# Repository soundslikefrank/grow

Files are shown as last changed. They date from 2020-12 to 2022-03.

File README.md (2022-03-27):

# GROW

A Eurorack genetic sequencer.

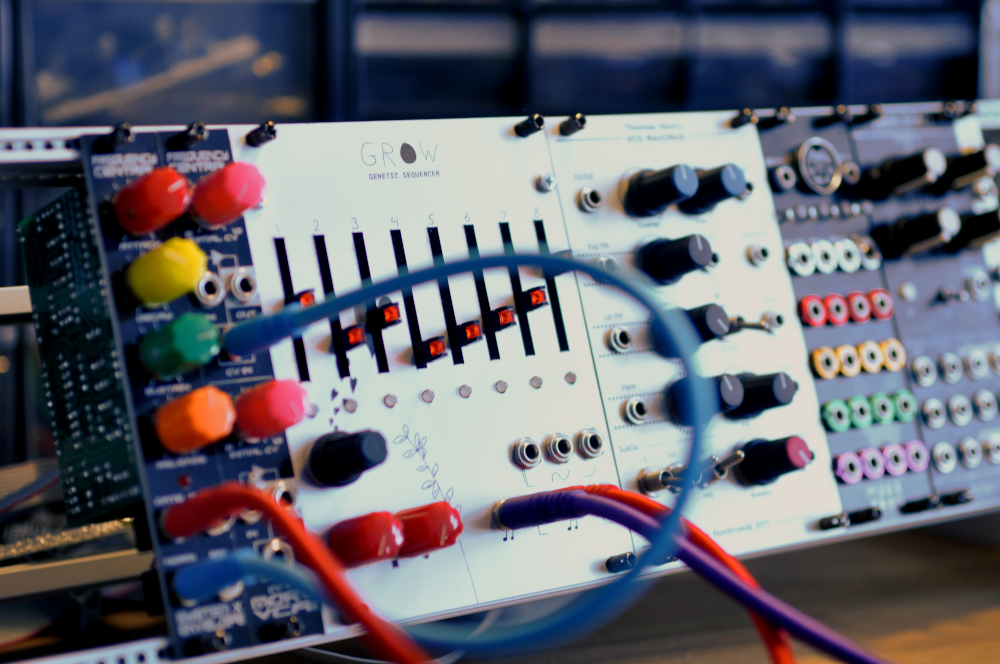
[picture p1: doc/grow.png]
grow


This repository serves as the home for its MCU code and hardware schematics.

There will be a lot more info soon.

## To build

```sh
git submodule update --init --recursive # if not cloned recursively
brew install cmake
brew install --cask gcc-arm-embedded
mkdir build && cd build
cmake -DCMAKE_TOOLCHAIN_FILE=../arm-none-eabi-gcc.cmake ..
make
```

## LICENSE

GNU General Public License v3.0

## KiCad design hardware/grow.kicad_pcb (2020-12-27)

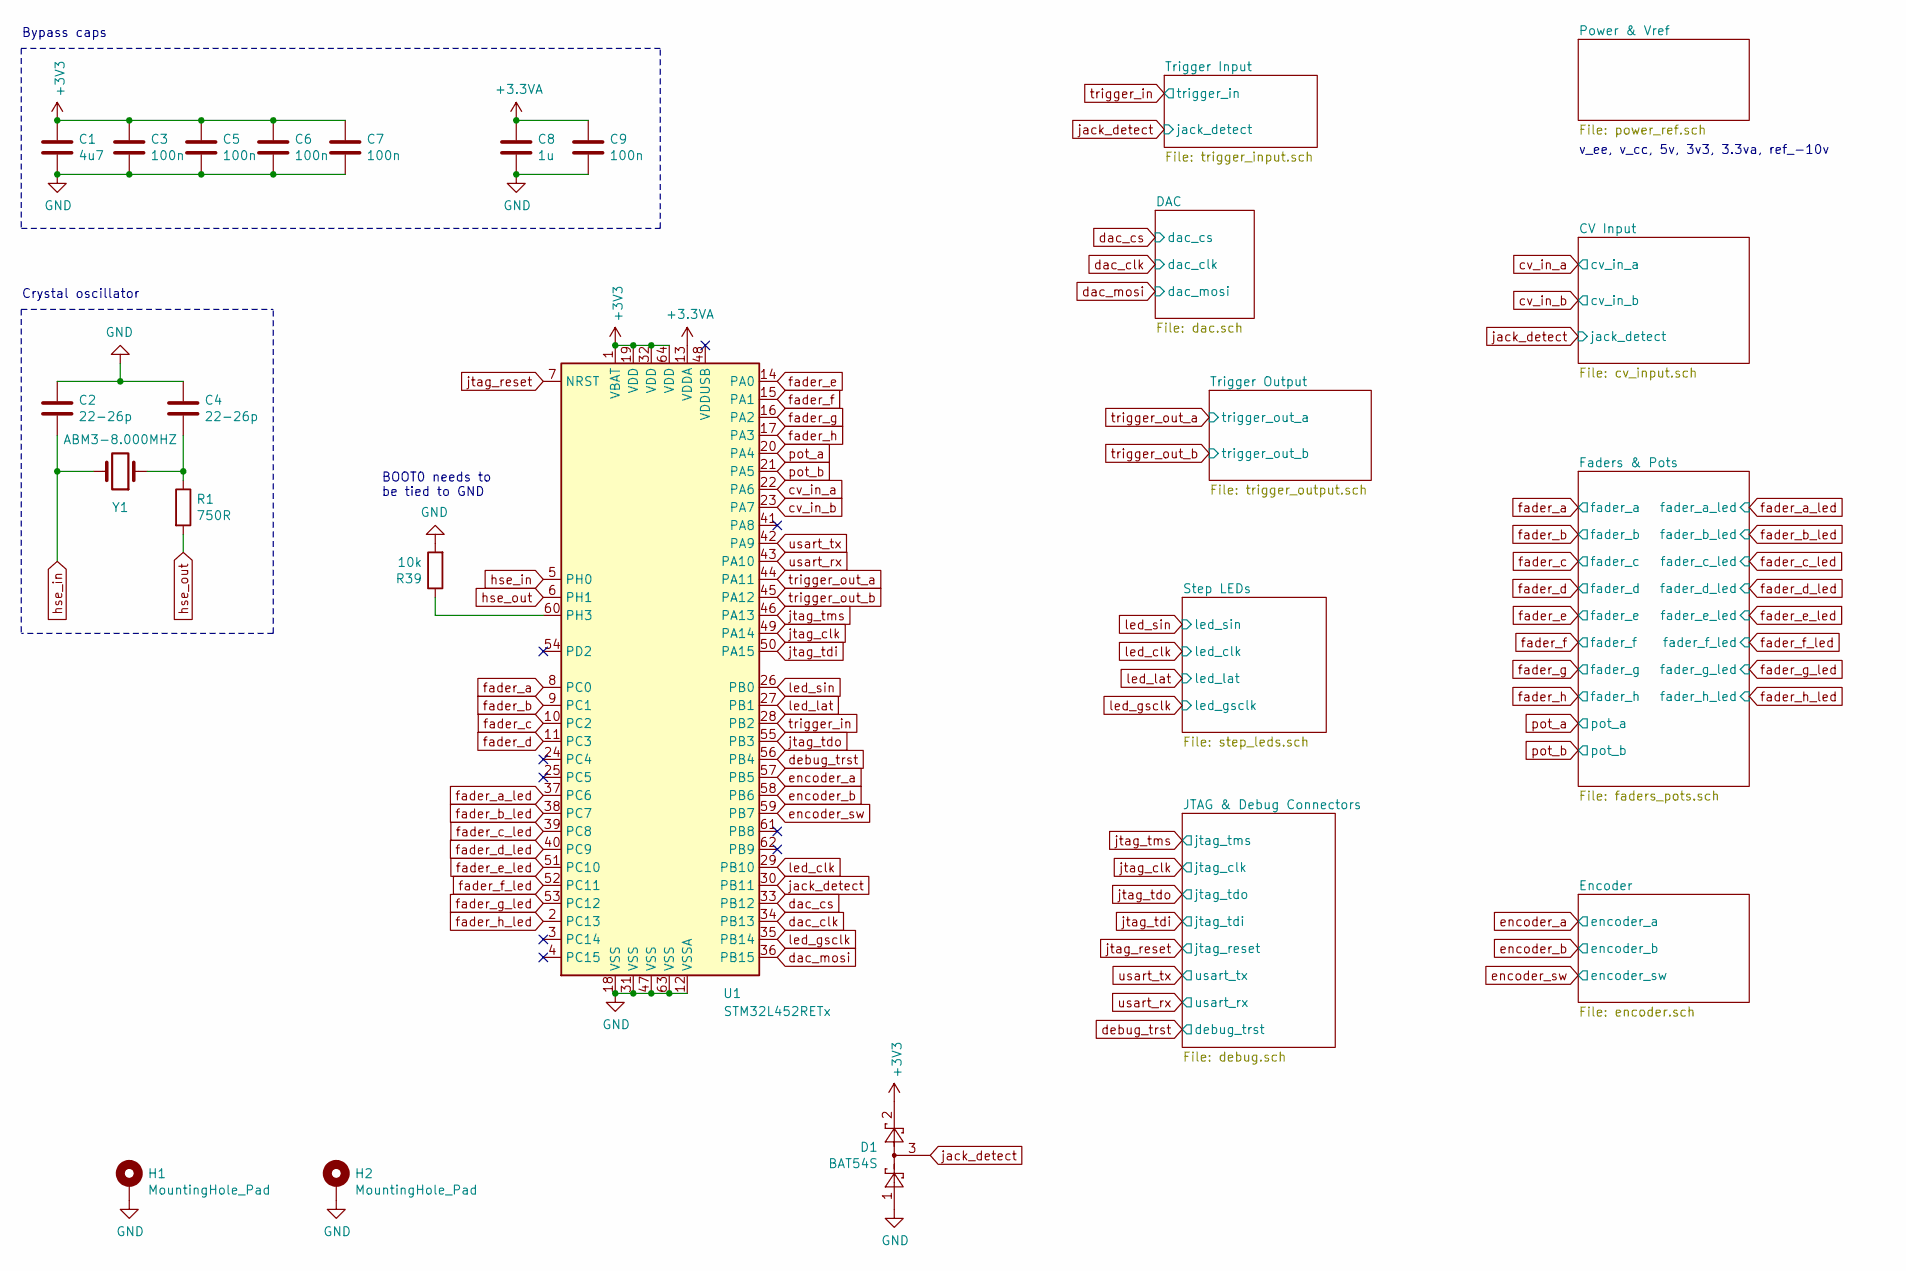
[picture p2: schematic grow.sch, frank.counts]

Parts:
C1: 4u7; C_0603_1608Metric; LCSC Part # C19666
C2, C4: 22-26p; C_0603_1608Metric; LCSC Part # C388039
C3, C5, C6, C7, C9: 100n; C_0603_1608Metric; LCSC Part # C14663
C8: 1u; C_0603_1608Metric; LCSC Part # C15849
D1: BAT54S; SOT-23
H1, H2: MountingHole_Pad; MountingHole_3.2mm_M3
R1: 750R; R_0603_1608Metric; LCSC Part # C23241
R39: 10k; R_0603_1608Metric; LCSC Part # C25804
U1: STM32L452RETx; LQFP-64_10x10mm_P0.5mm
Y1: ABM3-8.000MHZ; Crystal_SMD_Abracon_ABM3-2Pin_5.0x3.2mm_HandSoldering

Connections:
3v3a: C8.1, C9.1, U1.13 (VDDA); also elsewhere on the board
GND: C1.2, C2.1, C3.2, C4.1, C5.2, C6.2, C7.2, C8.2, C9.2, D1.1, H1.1, H2.1, R39.2, U1.12 (VSSA), U1.18 (VSS), U1.31 (VSS), U1.47 (VSS), U1.63 (VSS); also elsewhere on the board
unnamed: C4.2, R1.1, Y1.1
unnamed: R39.1, U1.60 (PH3)
cv_in_a: U1.22 (PA6); also elsewhere on the board
cv_in_b: U1.23 (PA7); also elsewhere on the board
dac_clk: U1.34 (PB13); also elsewhere on the board
dac_cs: U1.33 (PB12); also elsewhere on the board
dac_mosi: U1.36 (PB15); also elsewhere on the board
debug_trst: U1.56 (PB4); also elsewhere on the board
encoder_a: U1.57 (PB5); also elsewhere on the board
encoder_b: U1.58 (PB6); also elsewhere on the board
encoder_sw: U1.59 (PB7); also elsewhere on the board
fader_a: U1.8 (PC0); also elsewhere on the board
fader_a_led: U1.37 (PC6); also elsewhere on the board
fader_b: U1.9 (PC1); also elsewhere on the board
fader_b_led: U1.38 (PC7); also elsewhere on the board
fader_c: U1.10 (PC2); also elsewhere on the board
fader_c_led: U1.39 (PC8); also elsewhere on the board
fader_d: U1.11 (PC3); also elsewhere on the board
fader_d_led: U1.40 (PC9); also elsewhere on the board
fader_e: U1.14 (PA0); also elsewhere on the board
fader_e_led: U1.51 (PC10); also elsewhere on the board
fader_f: U1.15 (PA1); also elsewhere on the board
fader_f_led: U1.52 (PC11); also elsewhere on the board
fader_g: U1.16 (PA2); also elsewhere on the board
fader_g_led: U1.53 (PC12); also elsewhere on the board
fader_h: U1.17 (PA3); also elsewhere on the board
fader_h_led: U1.2 (PC13); also elsewhere on the board
hse_in: C2.2, U1.5 (PH0), Y1.2
hse_out: R1.2, U1.6 (PH1)
jack_detect: D1.3, U1.30 (PB11); also elsewhere on the board
jtag_clk: U1.49 (PA14); also elsewhere on the board
jtag_reset: U1.7 (NRST); also elsewhere on the board
jtag_tdi: U1.50 (PA15); also elsewhere on the board
jtag_tdo: U1.55 (PB3); also elsewhere on the board
jtag_tms: U1.46 (PA13); also elsewhere on the board
led_clk: U1.29 (PB10); also elsewhere on the board
led_gsclk: U1.35 (PB14); also elsewhere on the board
led_lat: U1.27 (PB1); also elsewhere on the board
led_sin: U1.26 (PB0); also elsewhere on the board
pot_a: U1.20 (PA4); also elsewhere on the board
pot_b: U1.21 (PA5); also elsewhere on the board
trigger_in: U1.28 (PB2); also elsewhere on the board
trigger_out_a: U1.44 (PA11); also elsewhere on the board
trigger_out_b: U1.45 (PA12); also elsewhere on the board
usart_rx: U1.43 (PA10); also elsewhere on the board
usart_tx: U1.42 (PA9); also elsewhere on the board

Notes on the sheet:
Bypass caps
Crystal oscillator
v_ee, v_cc, 5v, 3v3, 3.3va, ref_-10v
BOOT0 needs to be tied to GND

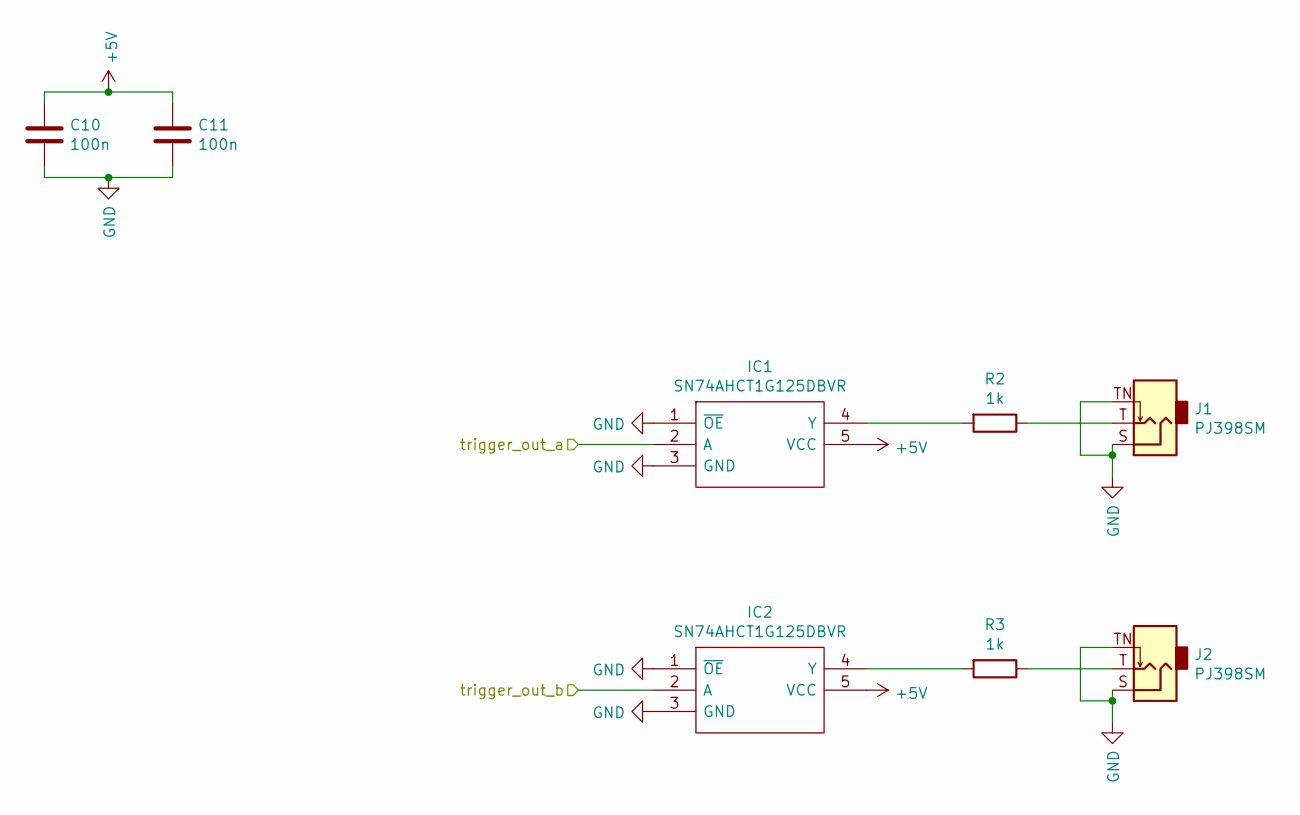
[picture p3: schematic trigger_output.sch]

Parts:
C10, C11: 100n; C_0603_1608Metric; LCSC Part # C14663
IC1, IC2: SN74AHCT1G125DBVR; SOT95P280X145-5N; Manufacturer_Part_Number SN74AHCT1G125DBVR; Mouser Part Number 595-SNAHCT1G125DBVR
J1, J2: PJ398SM; Jack_3.5mm_QingPu_WQP-PJ398SM_Vertical_CircularHoles
R2, R3: 1k; R_0603_1608Metric; LCSC Part # C21190

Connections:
+5V: C10.1, C11.1, IC1.5 (VCC), IC2.5 (VCC); also elsewhere on the board
GND: C10.2, C11.2, IC1.1 (~OE), IC1.3 (GND), IC2.1 (~OE), IC2.3 (GND), J1.S, J1.TN, J2.S, J2.TN; also elsewhere on the board
unnamed: IC1.4 (Y), R2.2
unnamed: IC2.4 (Y), R3.2
unnamed: J1.T, R2.1
unnamed: J2.T, R3.1
trigger_out_a: IC1.2 (A); also elsewhere on the board
trigger_out_b: IC2.2 (A); also elsewhere on the board

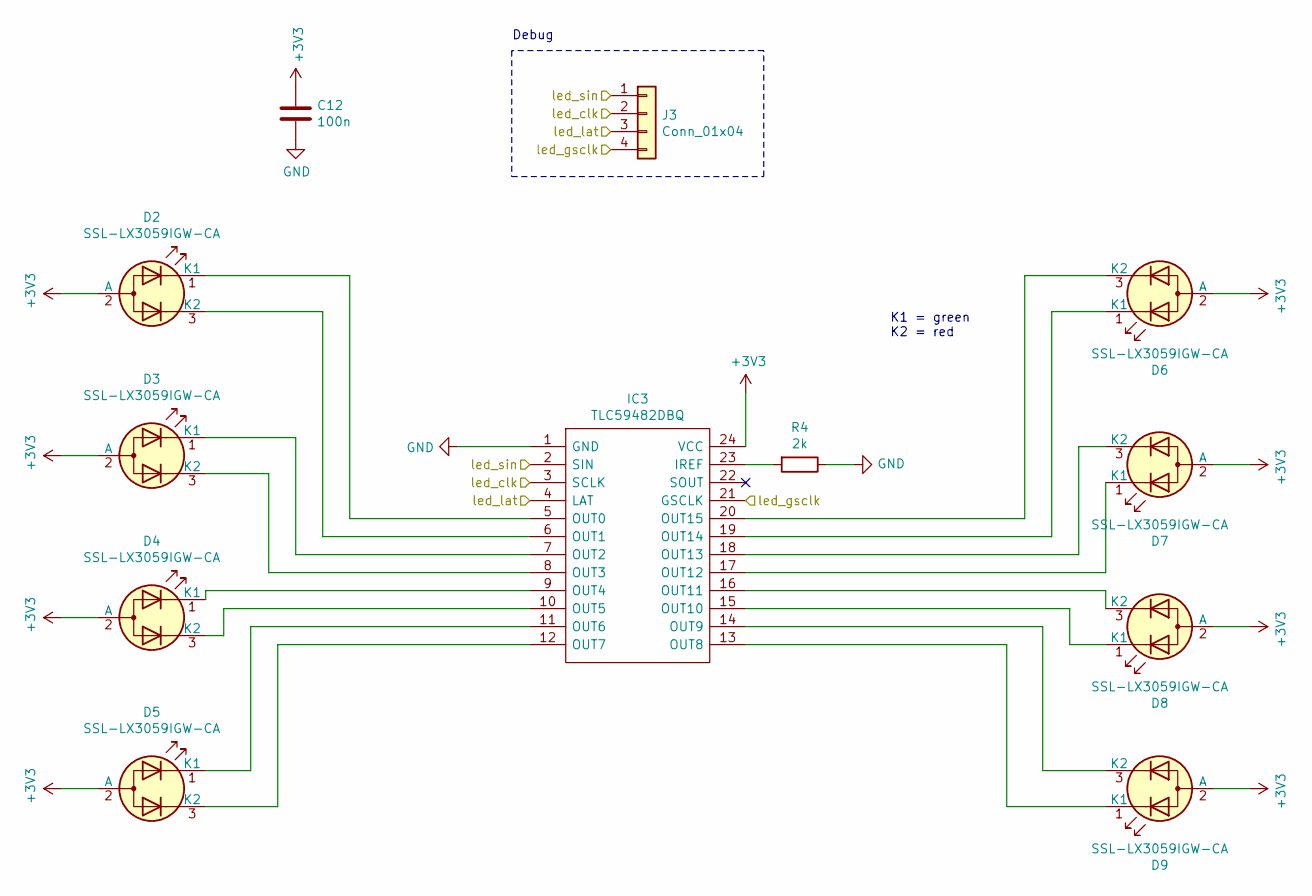
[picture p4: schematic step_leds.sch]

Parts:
C12: 100n; C_0603_1608Metric; LCSC Part # C14663
D2, D3, D4, D5, D6, D7, D8, D9: SSL-LX3059IGW-CA; LED_D3.0mm-3
IC3: TLC59482DBQ; SOP64P600X175-24N; Manufacturer_Part_Number TLC59482DBQ; Mouser Part Number 595-TLC59482DBQ
J3: Conn_01x04; PinHeader_1x04_P2.54mm_Vertical
R4: 2k; R_0603_1608Metric; LCSC Part # C22975

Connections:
GND: C12.2, IC3.1 (GND), R4.1; also elsewhere on the board
unnamed: D2.1 (K1), IC3.5 (OUT0)
unnamed: D2.3 (K2), IC3.6 (OUT1)
unnamed: D3.1 (K1), IC3.7 (OUT2)
unnamed: D3.3 (K2), IC3.8 (OUT3)
unnamed: D4.1 (K1), IC3.9 (OUT4)
unnamed: D4.3 (K2), IC3.10 (OUT5)
unnamed: D5.1 (K1), IC3.11 (OUT6)
unnamed: D5.3 (K2), IC3.12 (OUT7)
unnamed: D6.1 (K1), IC3.19 (OUT14)
unnamed: D6.3 (K2), IC3.20 (OUT15)
unnamed: D7.1 (K1), IC3.17 (OUT12)
unnamed: D7.3 (K2), IC3.18 (OUT13)
unnamed: D8.1 (K1), IC3.15 (OUT10)
unnamed: D8.3 (K2), IC3.16 (OUT11)
unnamed: D9.1 (K1), IC3.13 (OUT8)
unnamed: D9.3 (K2), IC3.14 (OUT9)
unnamed: IC3.23 (IREF), R4.2
led_clk: IC3.3 (SCLK), J3.2; also elsewhere on the board
led_gsclk: IC3.21 (GSCLK), J3.4; also elsewhere on the board
led_lat: IC3.4 (LAT), J3.3; also elsewhere on the board
led_sin: IC3.2 (SIN), J3.1; also elsewhere on the board

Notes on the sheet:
Debug
K1 = green K2 = red

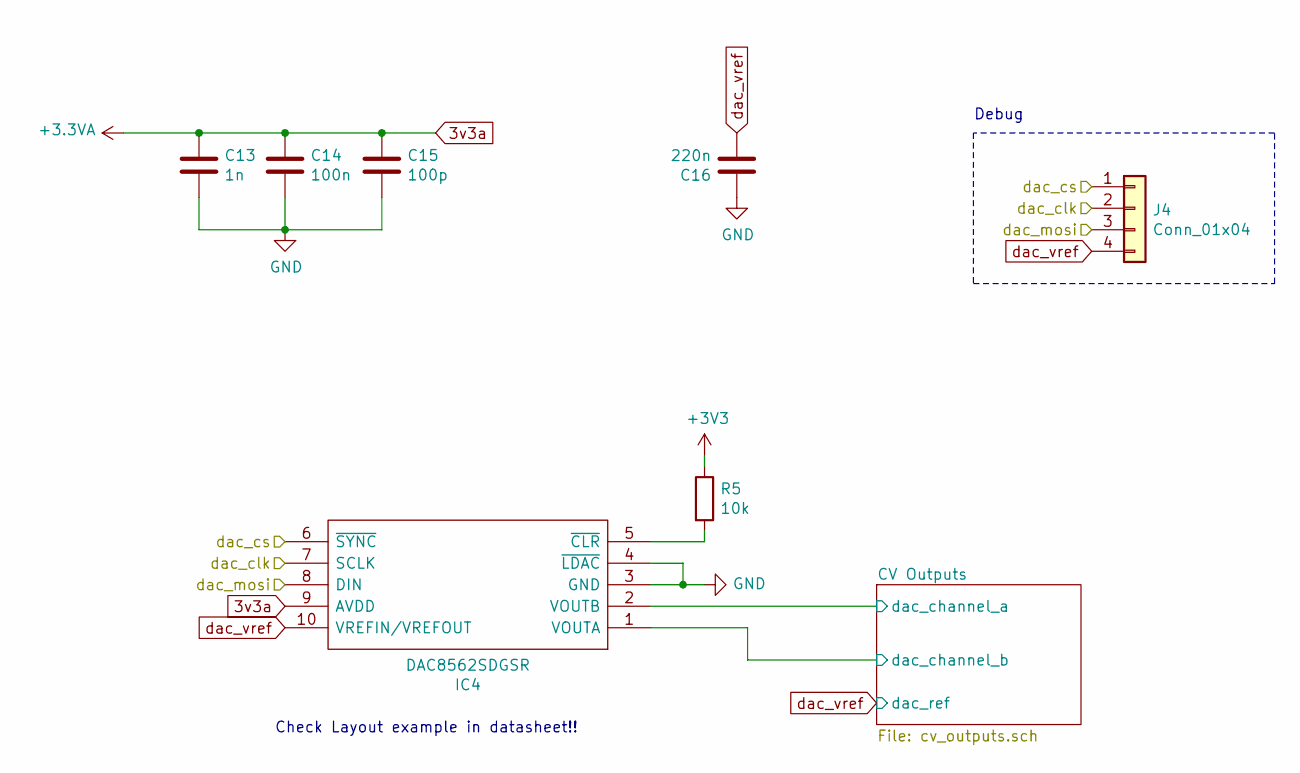
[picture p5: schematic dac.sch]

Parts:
C13: 1n; C_0603_1608Metric; LCSC Part # C1588
C14: 100n; C_0603_1608Metric; LCSC Part # C14663
C15: 100p; C_0603_1608Metric; LCSC Part # C14858
C16: 220n; C_0603_1608Metric; LCSC Part # C21120
IC4: DAC8562SDGSR; SOP50P490X110-10N; Manufacturer_Part_Number DAC8562SDGSR; Mouser Part Number 595-DAC8562SDGSR
J4: Conn_01x04; PinHeader_1x04_P2.54mm_Vertical
R5: 10k; R_0603_1608Metric; LCSC Part # C25804

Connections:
3v3a: C13.2, C14.1, C15.1, IC4.9 (AVDD); also elsewhere on the board
/DAC/CV Outputs/dac_channel_a: IC4.2 (VOUTB); also elsewhere on the board
/DAC/CV Outputs/dac_channel_b: IC4.1 (VOUTA); also elsewhere on the board
GND: C13.1, C14.2, C15.2, C16.2, IC4.3 (GND), IC4.4 (~LDAC); also elsewhere on the board
unnamed: IC4.5 (~CLR), R5.2
dac_clk: IC4.7 (SCLK), J4.2; also elsewhere on the board
dac_cs: IC4.6 (~SYNC), J4.1; also elsewhere on the board
dac_mosi: IC4.8 (DIN), J4.3; also elsewhere on the board
dac_vref: C16.1, IC4.10 (VREFIN/VREFOUT), J4.4; also elsewhere on the board

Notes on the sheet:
Check Layout example in datasheet!!
Debug

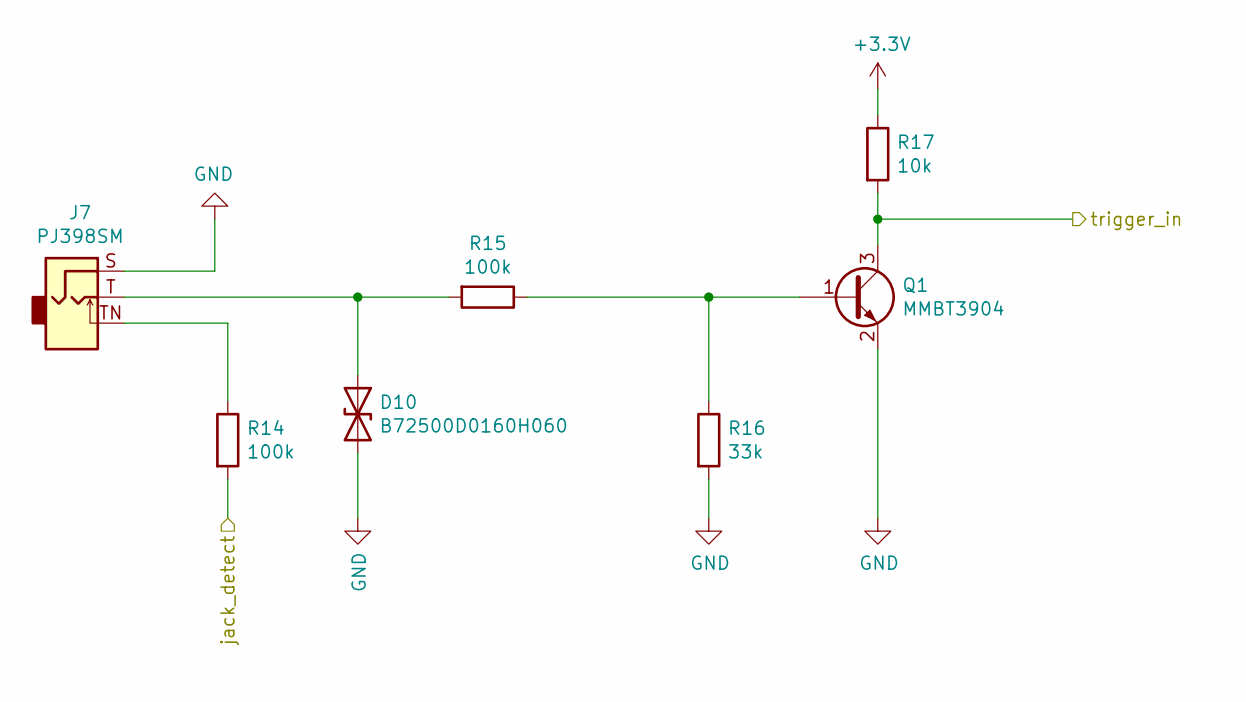
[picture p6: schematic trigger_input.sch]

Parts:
D10: B72500D0160H060; D_0603_1608Metric
J7: PJ398SM; Jack_3.5mm_QingPu_WQP-PJ398SM_Vertical_CircularHoles
Q1: MMBT3904; SOT-23; LCSC Part # C20526
R14, R15: 100k; R_0603_1608Metric; LCSC Part # C25803
R16: 33k; R_0603_1608Metric; LCSC Part # C4216
R17: 10k; R_0603_1608Metric; LCSC Part # C25804

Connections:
GND: D10.2 (A2), J7.S, Q1.2 (E), R16.2; also elsewhere on the board
unnamed: D10.1 (A1), J7.T, R15.2
unnamed: J7.TN, R14.1
unnamed: Q1.1 (B), R15.1, R16.1
jack_detect: R14.2; also elsewhere on the board
trigger_in: Q1.3 (C), R17.2; also elsewhere on the board

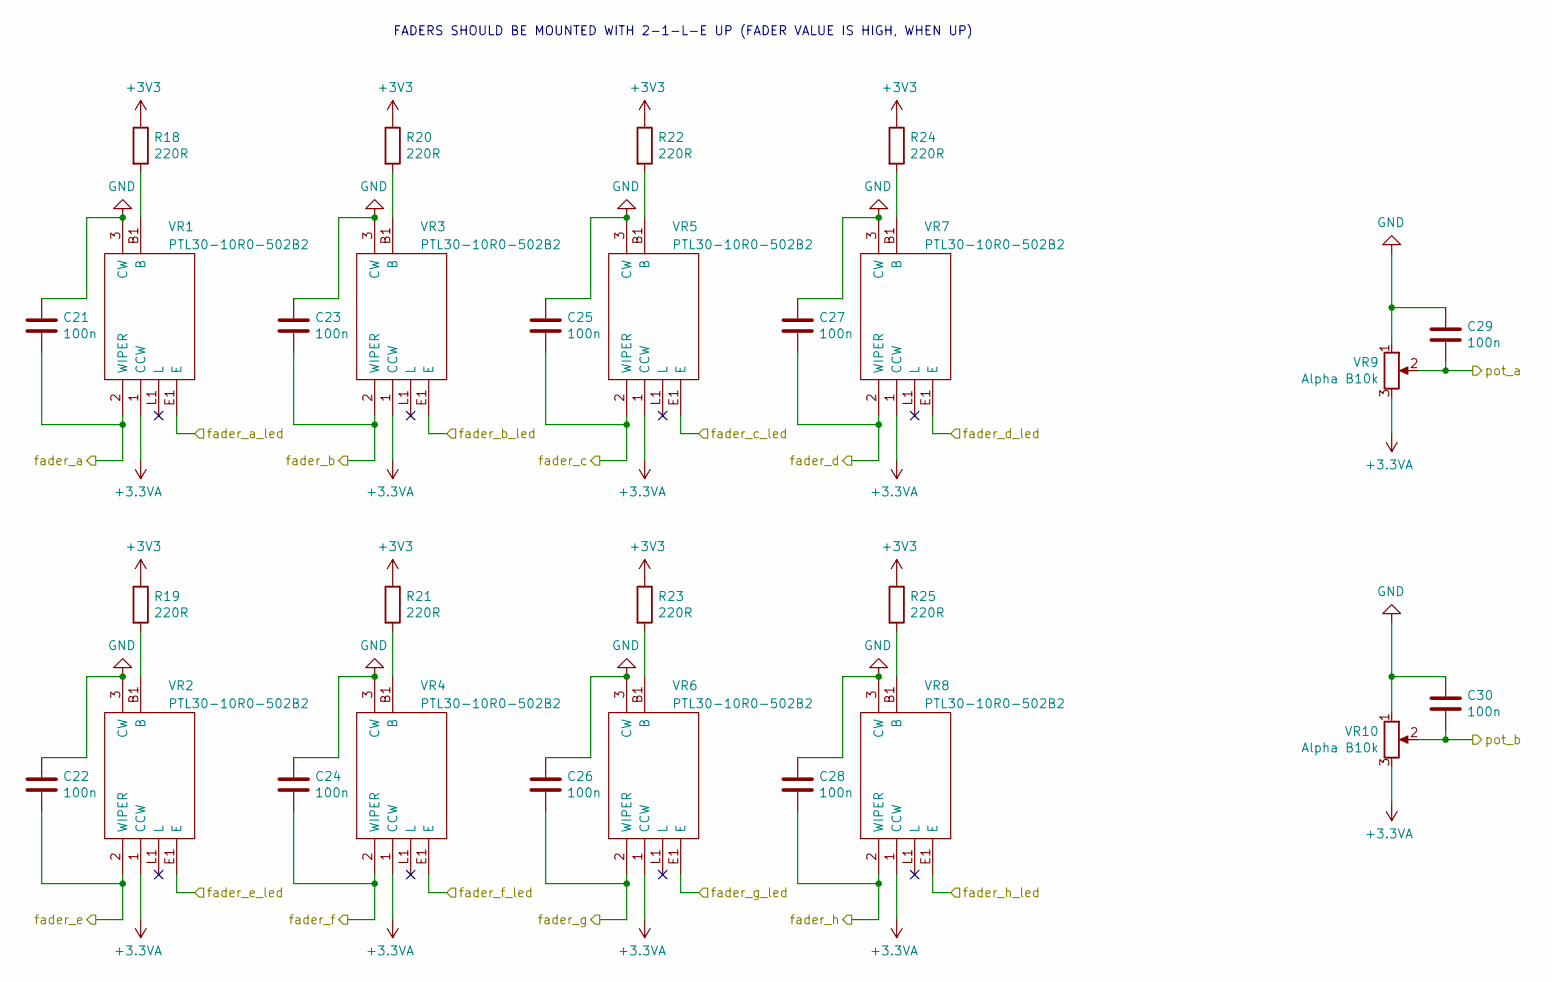
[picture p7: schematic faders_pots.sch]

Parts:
C21, C22, C23, C24, C25, C26, C27, C28, C29, C30: 100n; C_0603_1608Metric; LCSC Part # C14663
R18, R19, R20, R21, R22, R23, R24, R25: 220R; R_0603_1608Metric; LCSC Part # C22962
VR1, VR2, VR3, VR4, VR5, VR6, VR7, VR8: PTL30-10R0-502B2; PTL3010R1103B2; Manufacturer_Part_Number PTL30-10R0-502B2; Mouser Part Number 652-PTL30-10R0-502B2
VR9, VR10: Alpha B10k; Potentiometer_Alpha_RD901F-40-00D_Single_Vertical

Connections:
3v3a: VR1.1 (CCW), VR2.1 (CCW), VR3.1 (CCW), VR4.1 (CCW), VR5.1 (CCW), VR6.1 (CCW), VR7.1 (CCW), VR8.1 (CCW), VR9.3, VR10.3; also elsewhere on the board
GND: C21.1, C22.1, C23.1, C24.1, C25.1, C26.1, C27.1, C28.1, C29.1, C30.1, VR1.3 (CW), VR2.3 (CW), VR3.3 (CW), VR4.3 (CW), VR5.3 (CW), VR6.3 (CW), VR7.3 (CW), VR8.3 (CW), VR9.1, VR10.1; also elsewhere on the board
unnamed: R18.2, VR1.B1 (B)
unnamed: R19.2, VR2.B1 (B)
unnamed: R20.2, VR3.B1 (B)
unnamed: R21.2, VR4.B1 (B)
unnamed: R22.2, VR5.B1 (B)
unnamed: R23.2, VR6.B1 (B)
unnamed: R24.2, VR7.B1 (B)
unnamed: R25.2, VR8.B1 (B)
fader_a: C21.2, VR1.2 (WIPER); also elsewhere on the board
fader_a_led: VR1.E1 (E); also elsewhere on the board
fader_b: C23.2, VR3.2 (WIPER); also elsewhere on the board
fader_b_led: VR3.E1 (E); also elsewhere on the board
fader_c: C25.2, VR5.2 (WIPER); also elsewhere on the board
fader_c_led: VR5.E1 (E); also elsewhere on the board
fader_d: C27.2, VR7.2 (WIPER); also elsewhere on the board
fader_d_led: VR7.E1 (E); also elsewhere on the board
fader_e: C22.2, VR2.2 (WIPER); also elsewhere on the board
fader_e_led: VR2.E1 (E); also elsewhere on the board
fader_f: C24.2, VR4.2 (WIPER); also elsewhere on the board
fader_f_led: VR4.E1 (E); also elsewhere on the board
fader_g: C26.2, VR6.2 (WIPER); also elsewhere on the board
fader_g_led: VR6.E1 (E); also elsewhere on the board
fader_h: C28.2, VR8.2 (WIPER); also elsewhere on the board
fader_h_led: VR8.E1 (E); also elsewhere on the board
pot_a: C29.2, VR9.2; also elsewhere on the board
pot_b: C30.2, VR10.2; also elsewhere on the board

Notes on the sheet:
FADERS SHOULD BE MOUNTED WITH 2-1-L-E UP (FADER VALUE IS HIGH, WHEN UP)

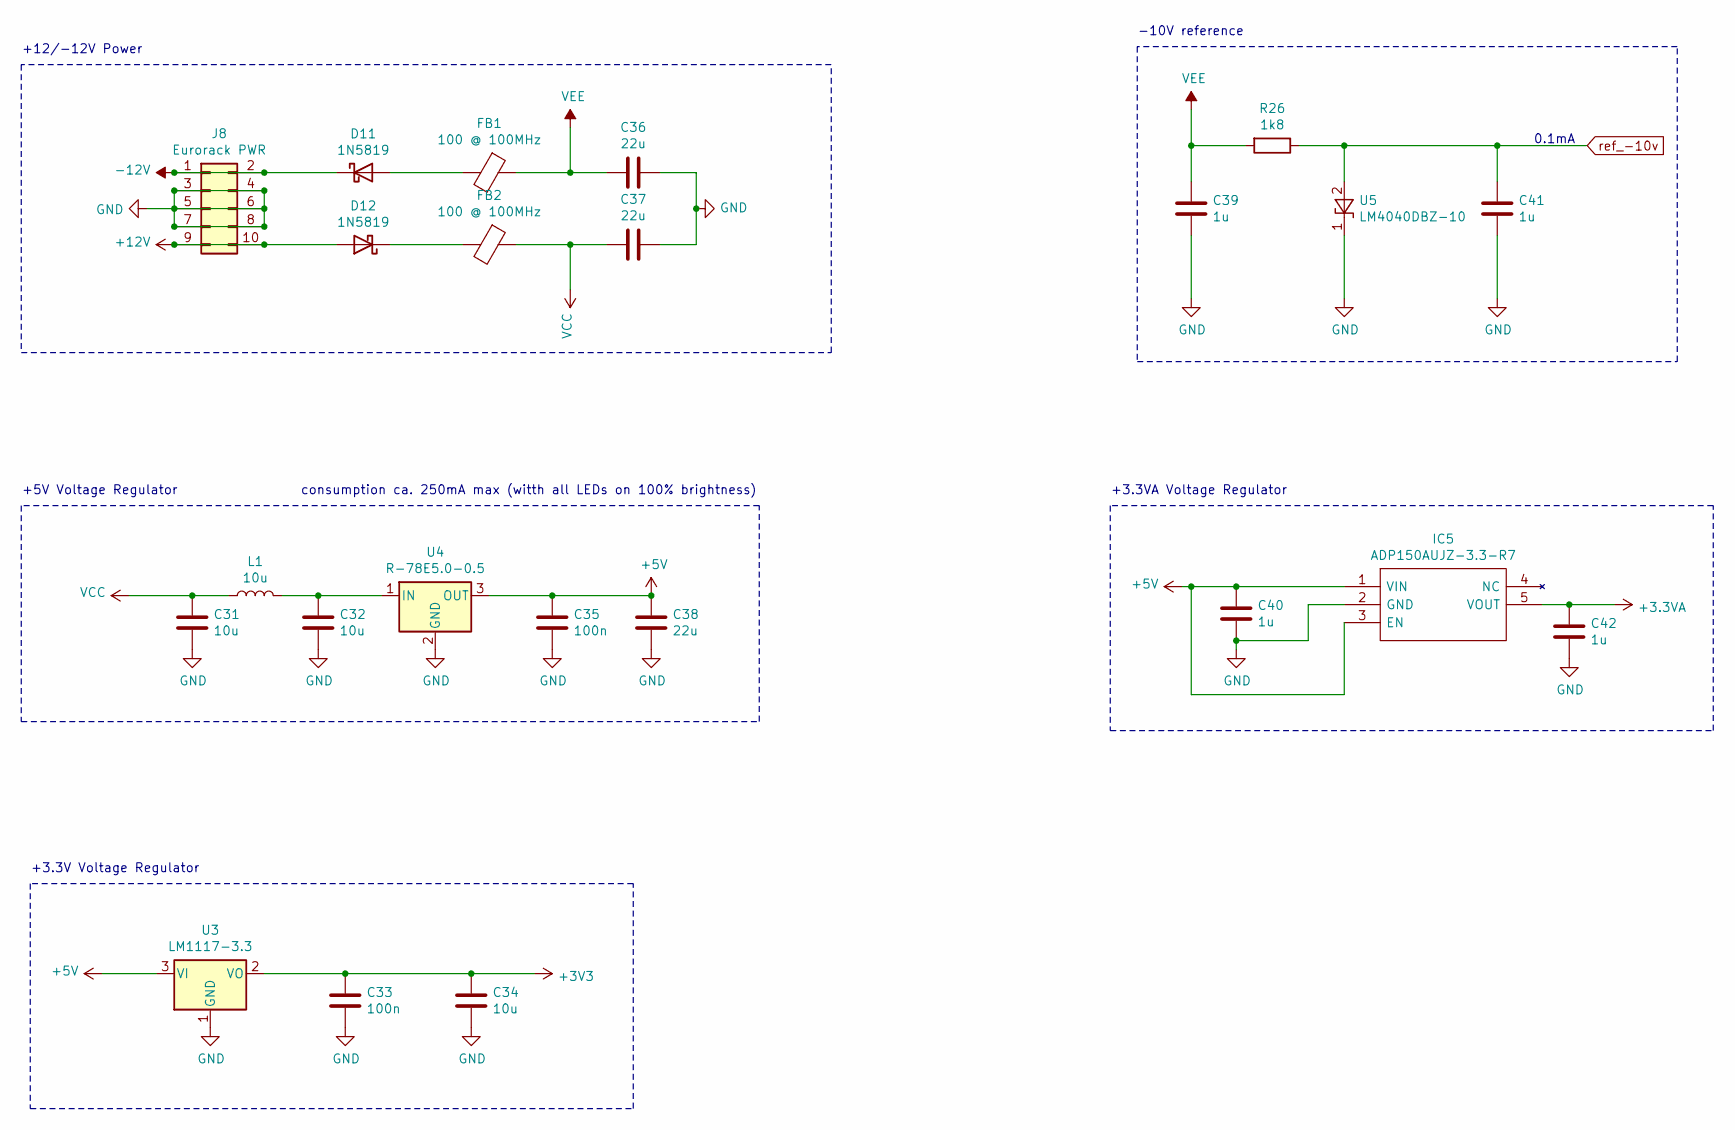
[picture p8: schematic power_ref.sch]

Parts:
C31, C32, C34: 10u; C_0805_2012Metric; LCSC Part # C15850
C33, C35: 100n; C_0603_1608Metric; LCSC Part # C14663
C36, C37, C38: 22u; C_0805_2012Metric; LCSC Part # C45783
C39, C40, C41, C42: 1u; C_0603_1608Metric; LCSC Part # C15849
D11, D12: 1N5819; D_SOD-123; LCSC Part # C8598
FB1, FB2: 100 @ 100MHz; L_0805_2012Metric; LCSC Part # C1015
IC5: ADP150AUJZ-3.3-R7; SOT95P280X100-5N; Manufacturer_Part_Number ADP150AUJZ-3.3-R7; Mouser Part Number 584-ADP150AUJZ-3.3R7
J8: Eurorack PWR; IDC-Header_2x05_P2.54mm_Vertical
L1: 10u; L_0805_2012Metric; LCSC Part # C1035
R26: 1k8; R_0603_1608Metric; LCSC Part # C4177
U3: LM1117-3.3; SOT-223; LCSC Part # C6186
U4: R-78E5.0-0.5; Converter_DCDC_RECOM_R-78E-0.5_THT
U5: LM4040DBZ-10; SOT-23

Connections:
3v3a: C42.1, IC5.5 (VOUT); also elsewhere on the board
+5V: C35.1, C38.2, C40.1, IC5.1 (VIN), IC5.3 (EN), U3.3 (VI), U4.3 (OUT); also elsewhere on the board
+12V: D12.2 (A), J8.9, J8.10
-12V: D11.1 (K), J8.1, J8.2
GND: C31.2, C32.1, C33.2, C34.2, C35.2, C36.1, C37.1, C38.1, C39.2, C40.2, C41.2, C42.2, IC5.2 (GND), J8.3, J8.4, J8.5, J8.6, J8.7, J8.8, U3.1 (GND), U4.2 (GND), U5.1 (K); also elsewhere on the board
unnamed: C32.2, L1.2, U4.1 (IN)
unnamed: D11.2 (A), FB1.2
unnamed: D12.1 (K), FB2.2
VCC: C31.1, C37.2, FB2.1, L1.1; also elsewhere on the board
VEE: C36.2, C39.1, FB1.1, R26.2; also elsewhere on the board
ref_-10v: C41.1, R26.1, U5.2 (A); also elsewhere on the board

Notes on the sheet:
-10V reference
0.1mA
+5V Voltage Regulator
+12/-12V Power
+3.3V Voltage Regulator
consumption ca. 250mA max (witth all LEDs on 100% brightness)
+3.3VA Voltage Regulator

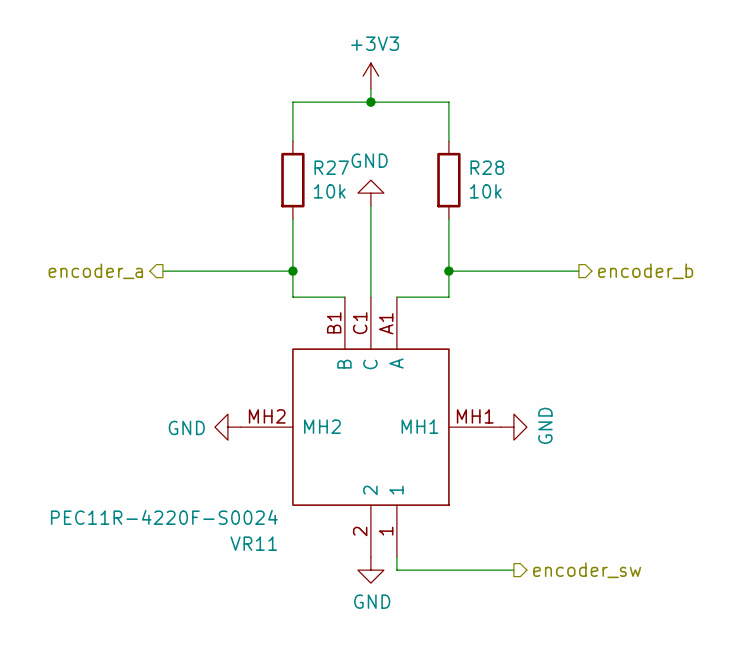
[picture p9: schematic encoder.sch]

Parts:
R27, R28: 10k; R_0603_1608Metric; LCSC Part # C25804
VR11: PEC11R-4220F-S0024; PEC11R4220FS0024; Manufacturer_Part_Number PEC11R-4220F-S0024; Mouser Part Number 652-PEC11R-4220F-S24

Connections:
GND: VR11.2, VR11.C1 (C), VR11.MH1, VR11.MH2; also elsewhere on the board
encoder_a: R27.2, VR11.B1 (B); also elsewhere on the board
encoder_b: R28.2, VR11.A1 (A); also elsewhere on the board
encoder_sw: VR11.1; also elsewhere on the board

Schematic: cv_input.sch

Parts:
C43, C44: 100p; C_0603_1608Metric; LCSC Part # C14858
C45: 100n; C_0603_1608Metric; LCSC Part # C14663
D13, D14: B72500D0160H060; D_0603_1608Metric
J9, J10: PJ398SM; Jack_3.5mm_QingPu_WQP-PJ398SM_Vertical_CircularHoles
R29, R30: 100k; R_0603_1608Metric; LCSC Part # C25803
R31, R32: 140k; R_0603_1608Metric
R33, R34: 200k; R_0603_1608Metric; LCSC Part # C25811
R35, R36: 33k; R_0603_1608Metric; LCSC Part # C4216
R37, R38: 100R; R_0603_1608Metric; LCSC Part # C22775
U6: MCP6002-xMS; SOIC-8_3.9x4.9mm_P1.27mm; LCSC Part # C7377

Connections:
GND: C45.2, D13.2 (A2), D14.2 (A2), J9.S, J10.S, U6.3 (+), U6.4 (V-), U6.5 (+); also elsewhere on the board
unnamed: C43.1, R31.1, R33.2, R35.2, U6.2 (-)
unnamed: C43.2, R35.1, R37.2, U6.1
unnamed: C44.1, R32.1, R34.2, R36.2, U6.6 (-)
unnamed: C44.2, R36.1, R38.2, U6.7
unnamed: D13.1 (A1), J9.T, R31.2
unnamed: D14.1 (A1), J10.T, R32.2
unnamed: J9.TN, R29.1
unnamed: J10.TN, R30.1
cv_in_a: R37.1; also elsewhere on the board
cv_in_b: R38.1; also elsewhere on the board
jack_detect: R29.2, R30.2; also elsewhere on the board
ref_-10v: R33.1, R34.1; also elsewhere on the board

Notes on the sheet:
-7V-+7V

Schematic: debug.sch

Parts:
J11: Conn_02x05_Odd_Even; PinHeader_2x05_P1.27mm_Vertical
J12: Conn_01x03; PinHeader_1x03_P2.54mm_Vertical
J13: Conn_01x01; PinHeader_1x01_P2.54mm_Vertical

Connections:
GND: J11.3, J11.5, J11.9, J12.3; also elsewhere on the board
debug_trst: J13.1; also elsewhere on the board
jtag_clk: J11.4; also elsewhere on the board
jtag_reset: J11.10; also elsewhere on the board
jtag_tdi: J11.8; also elsewhere on the board
jtag_tdo: J11.6; also elsewhere on the board
jtag_tms: J11.2; also elsewhere on the board
usart_rx: J12.2; also elsewhere on the board
usart_tx: J12.1; also elsewhere on the board

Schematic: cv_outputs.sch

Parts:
C17, C18: 100n; C_0603_1608Metric; LCSC Part # C14663
C19, C20: 10p; C_0603_1608Metric; LCSC Part # C1634
J5, J6: PJ398SM; Jack_3.5mm_QingPu_WQP-PJ398SM_Vertical_CircularHoles
R6: 22k; R_0603_1608Metric
R7: 51k; R_0603_1608Metric
R8, R9: 75k; R_0603_1608Metric
R10, R11: 200k; R_0603_1608Metric
R12, R13: 470R; R_0603_1608Metric; LCSC Part # C23179
U2: TL072; SOIC-8_3.9x4.9mm_P1.27mm; LCSC Part # C6961

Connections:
/DAC/CV Outputs/dac_channel_a: R8.2; also elsewhere on the board
/DAC/CV Outputs/dac_channel_b: R9.2; also elsewhere on the board
GND: C17.1, C18.1, J5.S, J5.TN, J6.S, J6.TN, R7.1; also elsewhere on the board
unnamed: C19.1, R12.2, U2.1
unnamed: C19.2, R8.1, R10.2, U2.2 (-)
unnamed: C20.1, R13.2, U2.7
unnamed: C20.2, R9.1, R11.2, U2.6 (-)
unnamed: J5.T, R10.1, R12.1
unnamed: J6.T, R11.1, R13.1
VCC: C17.2, U2.8 (V+); also elsewhere on the board
VEE: C18.2, U2.4 (V-); also elsewhere on the board
dac_vref: R6.2; also elsewhere on the board
ref_cv_out: R6.1, R7.2, U2.3 (+), U2.5 (+)

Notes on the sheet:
-2.4V - 6.4V

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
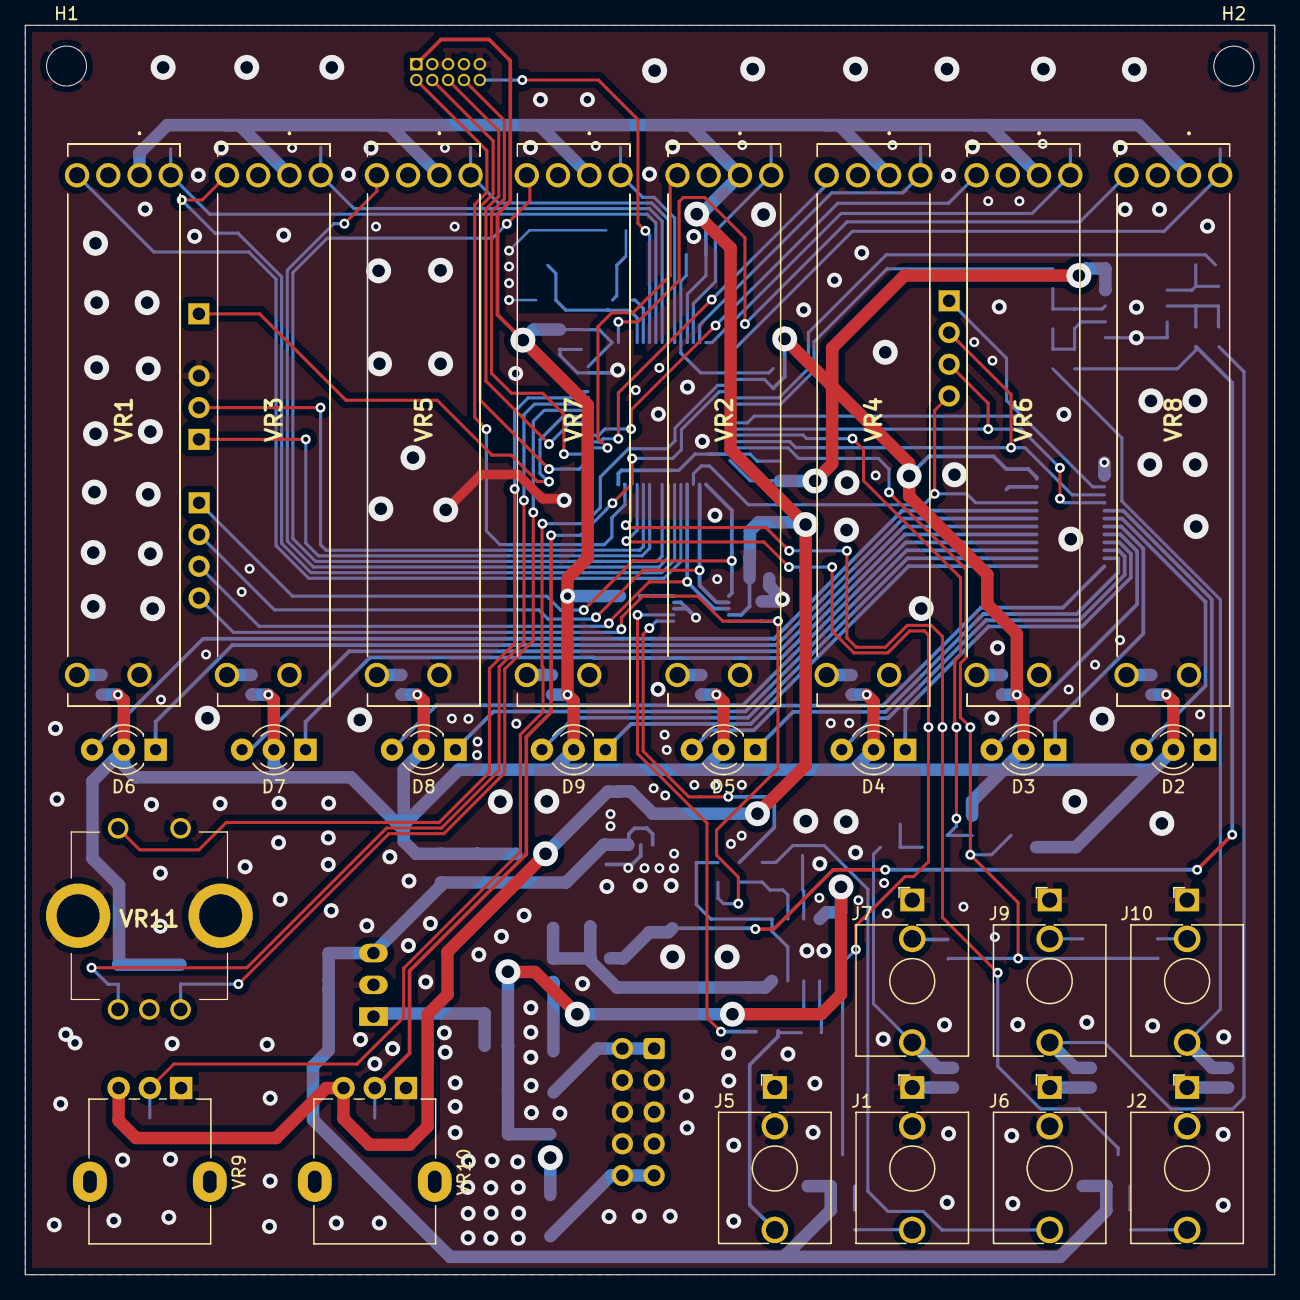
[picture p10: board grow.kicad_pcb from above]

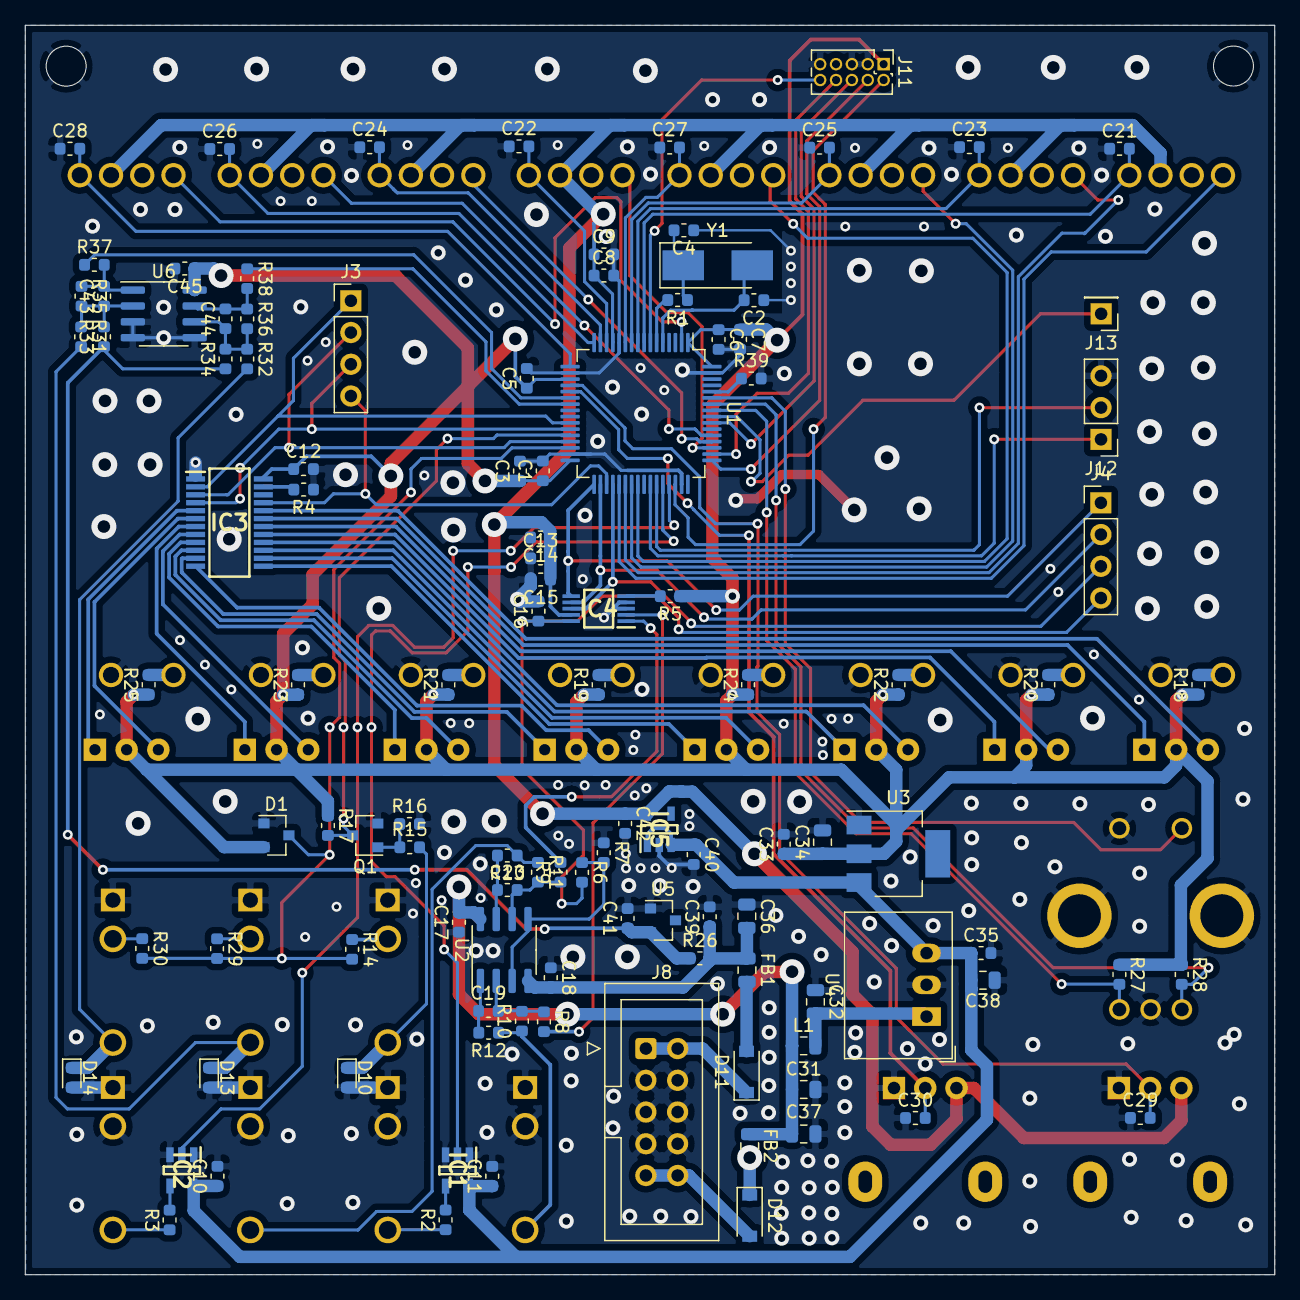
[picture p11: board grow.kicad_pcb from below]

Board: 2 copper layers, 100.0 x 100.0 mm, 140 parts (112 on the bottom side), 109 nets.

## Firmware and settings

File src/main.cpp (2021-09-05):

// Copyright 2020 <Christian Maniewski>

#include <math.h>
#include <stm32l4xx_hal.h>
#include <string.h>
#include <cstdio>
#include "drivers/adc.h"
#include "drivers/dac.h"
#include "drivers/eeprom.h"
#include "drivers/encoder.h"
#include "drivers/fader_led.h"
#include "drivers/jack_detect.h"
#include "drivers/led.h"
#include "drivers/tim_metronome.h"
#include "drivers/tim_ui.h"
#include "quantizer.h"
#include "sequencer.h"
#include "uart_debug.h"

// @TODO Apply
// https://cliutils.gitlab.io/modern-cmake/chapters/basics/structure.html

void Error_Handler() {}

void SystemClock_Config() {
  RCC_OscInitTypeDef RCC_OscInitStruct = {0};
  RCC_ClkInitTypeDef RCC_ClkInitStruct = {0};
  RCC_PeriphCLKInitTypeDef PeriphClkInit = {0};

  /** Initializes the RCC Oscillators according to the specified parameters
   * in the RCC_OscInitTypeDef structure.
   */
  RCC_OscInitStruct.OscillatorType = RCC_OSCILLATORTYPE_HSE;
  RCC_OscInitStruct.HSEState = RCC_HSE_ON;
  RCC_OscInitStruct.PLL.PLLState = RCC_PLL_ON;
  RCC_OscInitStruct.PLL.PLLSource = RCC_PLLSOURCE_HSE;
  RCC_OscInitStruct.PLL.PLLM = 1;
  RCC_OscInitStruct.PLL.PLLN = 10;
  RCC_OscInitStruct.PLL.PLLP = RCC_PLLP_DIV7;
  RCC_OscInitStruct.PLL.PLLQ = RCC_PLLQ_DIV2;
  RCC_OscInitStruct.PLL.PLLR = RCC_PLLR_DIV2;
  if (HAL_RCC_OscConfig(&RCC_OscInitStruct) != HAL_OK) {
    Error_Handler();
  }
  /** Initializes the CPU, AHB and APB buses clocks
   */
  RCC_ClkInitStruct.ClockType = RCC_CLOCKTYPE_HCLK | RCC_CLOCKTYPE_SYSCLK |
                                RCC_CLOCKTYPE_PCLK1 | RCC_CLOCKTYPE_PCLK2;
  RCC_ClkInitStruct.SYSCLKSource = RCC_SYSCLKSOURCE_PLLCLK;
  RCC_ClkInitStruct.AHBCLKDivider = RCC_SYSCLK_DIV1;
  RCC_ClkInitStruct.APB1CLKDivider = RCC_HCLK_DIV1;
  RCC_ClkInitStruct.APB2CLKDivider = RCC_HCLK_DIV1;

  if (HAL_RCC_ClockConfig(&RCC_ClkInitStruct, FLASH_LATENCY_2) != HAL_OK) {
    Error_Handler();
  }
  PeriphClkInit.PeriphClockSelection = RCC_PERIPHCLK_USART1 | RCC_PERIPHCLK_ADC;
  PeriphClkInit.Usart1ClockSelection = RCC_USART1CLKSOURCE_PCLK2;
  PeriphClkInit.AdcClockSelection = RCC_ADCCLKSOURCE_SYSCLK;
  if (HAL_RCCEx_PeriphCLKConfig(&PeriphClkInit) != HAL_OK) {
    Error_Handler();
  }
  /** Enables the Clock Security System
   */
  HAL_RCC_EnableCSS();
  /** Configure the main internal regulator output voltage
   */
  if (HAL_PWREx_ControlVoltageScaling(PWR_REGULATOR_VOLTAGE_SCALE1) != HAL_OK) {
    Error_Handler();
  }
}

// @TODO move to a different file?
enum EEPROM_STORE {
  STORE_CALIB_DAC_A_QUAD,
  STORE_CALIB_DAC_A_LIN,
  STORE_CALIB_DAC_A_CONST,
  STORE_CALIB_DAC_B_QUAD,
  STORE_CALIB_DAC_B_LIN,
  STORE_CALIB_DAC_B_CONST,
  STORE_CALIB_CV_IN_A_LIN,
  STORE_CALIB_CV_IN_A_CONST,
  STORE_CALIB_CV_IN_B_LIN,
  STORE_CALIB_CV_IN_B_CONST
};

int main() {
  HAL_Init();
  SystemClock_Config();
  HUART1_Init();

  Encoder.Init();
  JackDetect.Init();
  MetronomeTimer.Init();
  UITimer.Init();
  ADC.Init();
  FaderLED.Init();
  LED.Init();
  _DAC.Init();

  char msg[100] = "Hello, otter";

  uint16_t counter;
  uint8_t step;
  uint16_t bpm = 120;
  // @TODO don't have that in here
  int8_t encoderValue = 0;
  float tempCalibDacA;

  /* ----------------- CALIBRATION STUFF ------------------------ */

  EEPROM.Init();

  // @TODO move this to a different file
  // Calibration mode. Hold encoder button while turning on
  if (Encoder.GetRawSwitchState()) {
    // @TODO wait here while (encoder is not null)
    LED.SetX(0, LED_COLOR_GREEN, LED_MAX_BRIGHTNESS);
    LED.Set(7, LED_COLOR_RED, LED_MAX_BRIGHTNESS);
    JackDetect.ToggleCalibration();
    while (true) {
      if (UITimer.Tick()) {
        LED.Update();
        encoderValue += Encoder.ReadEncoder();
      }
      // @TODO more calibration logic here
      if (Encoder.ReadSwitch() == BUTTON_STATE_PRESS) {
        JackDetect.ToggleCalibration();
        EEPROM.WriteFloat(STORE_CALIB_DAC_A_QUAD, 2.87784e-09);
        break;
      }
    }
  }

  tempCalibDacA = EEPROM.ReadFloat(STORE_CALIB_DAC_A_QUAD);
  EEPROM.DeInit();

  /* ----------------- CALIBRATION STUFF END -------------------- */

  MetronomeTimer.SetBPM(bpm);
  Quantizer.SetScale(NOTE_E, KEY_PENTATONIC_MINOR, NOTE_E, 2, 1);
  Sequencer.Start();

  while (true) {
    if (UITimer.Tick()) {
      bpm += Encoder.ReadEncoder();
      counter = 4 * ADC.GetValue(9);
      LED.SetX(step % 8, LED_COLOR_YELLOW, counter);
      /* if (Encoder.ReadSwitch() == BUTTON_STATE_LONGPRESS) { */
      /*   counter = 1; */
      /* } */
      LED.Update();
    }
    if (MetronomeTimer.Tick()) {
      step = Sequencer.NextStep();
      float voltage = Quantizer.GetQuantizedVoltage(ADC.GetValueN(step % 8));
      _DAC.SetVoltage(0, voltage);
      _DAC.SetVoltage(1, 3.0F);
      MetronomeTimer.SetBPM(bpm);
      auto isPluggedIn = static_cast<uint8_t>(JackDetect.IsPluggedIn(INPUT_JACK_CV_1));
      sprintf(msg, "voltage%d: %.3f, plugged in: %d\r\n", step, voltage,
              isPluggedIn);
      HAL_UART_Transmit(&huart1, reinterpret_cast<uint8_t*>(msg), strlen(msg),
                        HAL_MAX_DELAY);
    }
  }
}

extern "C" {
// @TODO: put this somewhere sane?
void HAL_MspInit(void) {
  __HAL_RCC_SYSCFG_CLK_ENABLE();
  __HAL_RCC_PWR_CLK_ENABLE();
}
}

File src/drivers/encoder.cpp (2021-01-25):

// Copyright 2020 Christian Maniewski.
//
// Read encoder w/ switch

#include "drivers/encoder.h"
#include <stm32l4xx_hal.h>
#include "util.h"

EncoderClass::EncoderClass() = default;

void EncoderClass::Init() {
  GPIO_InitTypeDef igpio = {0};

  __HAL_RCC_GPIOB_CLK_ENABLE();

  igpio.Pin = ENCODER_PIN_CLK | ENCODER_PIN_DATA;
  igpio.Mode = GPIO_MODE_INPUT;
  igpio.Pull = GPIO_NOPULL;
  igpio.Speed = GPIO_SPEED_FREQ_LOW;
  HAL_GPIO_Init(ENCODER_PORT, &igpio);

  igpio.Pin = ENCODER_PIN_SW;
  igpio.Pull = GPIO_PULLUP;
  HAL_GPIO_Init(ENCODER_PORT, &igpio);
}

int8_t EncoderClass::ReadEncoder() {
  // Left-shift last state and read new state
  transitionState_ <<= 2;
  // @TODO this looks just weird
  transitionState_ |=
      ((uint8_t)(!(bool)HAL_GPIO_ReadPin(ENCODER_PORT, ENCODER_PIN_CLK)) << 1);
  transitionState_ |=
      (uint8_t)(!(bool)HAL_GPIO_ReadPin(ENCODER_PORT, ENCODER_PIN_DATA));

  // Clear first four bits (our array just has 16 entries)
  transitionState_ &= 0x0f;

  // Check if valid state found
  if (encoderStates_[transitionState_]) {
    // We are expecting a full cycle, either CW or CCW, that is
    // 11 -> 10, 10 -> 00, 00 -> 01, 01 -> 11 (CW) or
    // 01 -> 00, 00 -> 10, 10 -> 11, 11 -> 01 (CCW)
    // Store the last four transition bits
    cycleCompare_ <<= 4;
    cycleCompare_ |= transitionState_;
    // We're just looking at the last byte to be a bit more generous
    if ((cycleCompare_ & 0xff) == 0b10111101) {
      // Probabl CCW (see above)
      return -1;
    }
    if ((cycleCompare_ & 0xff) == 0b00010111) {
      // Probably CW (see above)
      return 1;
    }
  }
  return 0;
};

bool EncoderClass::GetRawSwitchState() {
  // Switch is implemented as a current sink
  return !(bool)HAL_GPIO_ReadPin(ENCODER_PORT, ENCODER_PIN_SW);
}

ButtonState EncoderClass::ReadSwitch() {
  if (buttonSampleIdx_ == BUTTON_SAMPLE_SIZE) {
    buttonSampleIdx_ = 0;
    if (buttonSamples_) {
      // We're still going!
      buttonLongPressCounter_ =
          clamp(buttonLongPressCounter_ + 1, 0, UINT16_MAX);
    } else if (buttonLongPressCounter_) {
      if (buttonLongPressCounter_ > ENCODER_BUTTON_LONGPRESS_THRESHOLD) {
        buttonLongPressCounter_ = 0;
        return BUTTON_STATE_LONGPRESS;
      }
      // Long press counter started but we don't have presses anymore. It's a
      // short press
      buttonLongPressCounter_ = 0;
      return BUTTON_STATE_PRESS;
    }
    buttonSamples_ = 0;
  }
  buttonSamples_ |= (uint8_t)GetRawSwitchState() << buttonSampleIdx_;
  buttonSampleIdx_++;
  return BUTTON_STATE_IDLE;
}

EncoderClass Encoder;

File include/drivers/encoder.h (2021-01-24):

// Copyright 2020 Christian Maniewski <code@chmanie.com>

#ifndef ENCODER_H
#define ENCODER_H

#include <stm32l4xx_hal.h>

#define ENCODER_PORT GPIOB
#define ENCODER_PIN_CLK GPIO_PIN_5
#define ENCODER_PIN_DATA GPIO_PIN_6
#define ENCODER_PIN_SW GPIO_PIN_7
#define BUTTON_SAMPLE_SIZE 8
// 2 seconds at 4kHz sample rate (thresh = 2s / (sampleSize * 4kHz))
#define ENCODER_BUTTON_LONGPRESS_THRESHOLD 1000

enum ButtonState {
  BUTTON_STATE_IDLE,
  BUTTON_STATE_PRESS,
  BUTTON_STATE_LONGPRESS,
};

class EncoderClass {
 private:
  const bool encoderStates_[16] = {false, true, true, false, true,  false,
                                   false, true, true, false, false, true,
                                   false, true, true, false};

  uint8_t transitionState_ = 0;
  int16_t cycleCompare_ = 0;
  uint8_t buttonSamples_ = 0;
  uint8_t buttonSampleIdx_ = 0;
  uint16_t buttonLongPressCounter_ = 0;

 public:
  EncoderClass();
  void Init();
  int8_t ReadEncoder();
  bool GetRawSwitchState();
  ButtonState ReadSwitch();
};

extern EncoderClass Encoder;

#endif  // ENCODER_H

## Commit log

2020-04-22 LED switching working
2020-04-24 Fader, DAC, LEDs working
2020-05-03 Add first version of timer-based metronome
2020-05-04 Use Metronome instead millis for main loop
2020-05-04 Add kicad files
    [frank_counts.kicad_pcb, frank_counts.sch]
2020-05-04 Wire up all components
    [frank_counts.sch]
2020-05-23 Name some resistors
    [frank_counts.sch]
2020-05-31 Start v2 of schematic, using STM32
    [dac.sch, frank_counts.sch, trigger_input.sch]
2020-07-05 Update schematics
    [dac.sch, frank_counts.sch, trigger_input.sch]
2020-07-17 Move to STM32
2020-07-17 Rewrite Metronome for STM32F3
2020-07-17 Switch to TIM2 for more precision!
2020-07-19 Timer based DMA LEDs
2020-09-08 Move uart_debug
2020-09-09 Add DAC driver
2020-09-10 Revise fader LED driver
2020-09-11 Timer changes
    Add UI timer
    Change metronome to driver
    Use global interrupt file
2020-09-11 Move systick handler to interrupt file
2020-09-13 Add UI ADC
2020-09-21 Use TIM3 to trigger UI ADC conversion
2020-09-25 Adjust code for stm32f302 target
2020-11-14 Use fader LEDs with current sink
2020-11-18 Switch to STM32F302RB
2020-11-19 Add kicad gitignore entries
2020-11-19 Add CV-out schematics
    [cv_outputs.sch, dac.sch, frank_counts.sch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]
2020-11-19 Translate raw fader value to voltage
2020-12-06 Add CV inputs schematics
    [cv_input.sch, cv_outputs.sch, dac.sch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]
2020-12-06 Use STM32L452RE MCU
2020-12-08 Build succeeds after l452 migration
    most probably not working yet
    [adc_ui.cpp]
2020-12-08 Use external oscillator, adjust tim2 clock
    [main.cpp, tim_metronome.cpp]
2020-12-09 Use GPIOC for fader LEDs
2020-12-09 Use correct pins for USART1
    [main.cpp]
2020-12-09 Repair ADC read
2020-12-09 Put back voltage calculation
2020-12-10 Use DAC8564
    [dac.sch]
2020-12-12 Adjust CV-ins
    [cv_input.sch, cv_outputs.sch, dac.sch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]
2020-12-12 Add LED driver, GSCLK
2020-12-17 Add more schematics:
    - Faders
    - Step LEDs
    - Trigger output
    [cv_input.sch, cv_outputs.sch, dac.sch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]
2020-12-17 Tiny LED class adjustments
2020-12-18 Add encoder and pots
    [cv_input.sch, cv_outputs.sch, dac.sch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]
2020-12-22 Reduce sample time to match timer speed
2020-12-24 Minor adjustments to schematics before PCB
    [cv_input.sch, cv_outputs.sch, dac.sch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]
2020-12-24 Add PCB design
    [frank_counts.kicad_pcb]
2020-12-27 Last adjustments to hardware before v0.1 release
    [cv_input.sch, cv_outputs.sch, dac.sch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]
2020-12-27 Improve LED GSCLK timing
2020-12-27 Implement LED state and set function
    [step_leds.sch]
2020-12-28 Use interrupt mode for qspi
2020-12-28 Use DMA for QSPI
2020-12-28 Use external handlers for all drivers
2020-12-29 Use interrupt mode for spi
2020-12-29 Soft reset DAC on initialisation
    [dac.cpp, main.cpp]
2020-12-29 Re-adjust resistor values for CV-out
    [cv_outputs.sch]
2021-01-10 Add pwm driven trigger output
2021-01-16 LED driver improvements
2021-01-24 Calibrate for the v0.2 prototype
2021-01-24 Add ADC calibration
2021-01-24 Use polynomial regression for DAC calibration
2021-01-25 Improve clamps and CONSTRAINs
2021-01-25 Use float for DAC voltage setter
2021-01-26 Add eeprom storage driver
2021-01-29 Adjust GPIO pin for trigger jack detect, test
2021-01-29 Rename to ADC
2021-09-05 Improve docs, minor fixes
    [main.cpp]
